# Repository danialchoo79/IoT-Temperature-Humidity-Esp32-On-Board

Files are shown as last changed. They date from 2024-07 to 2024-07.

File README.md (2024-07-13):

Schematic
PCB-Layout
3D-Front
3D-Back

Credit: made by morten

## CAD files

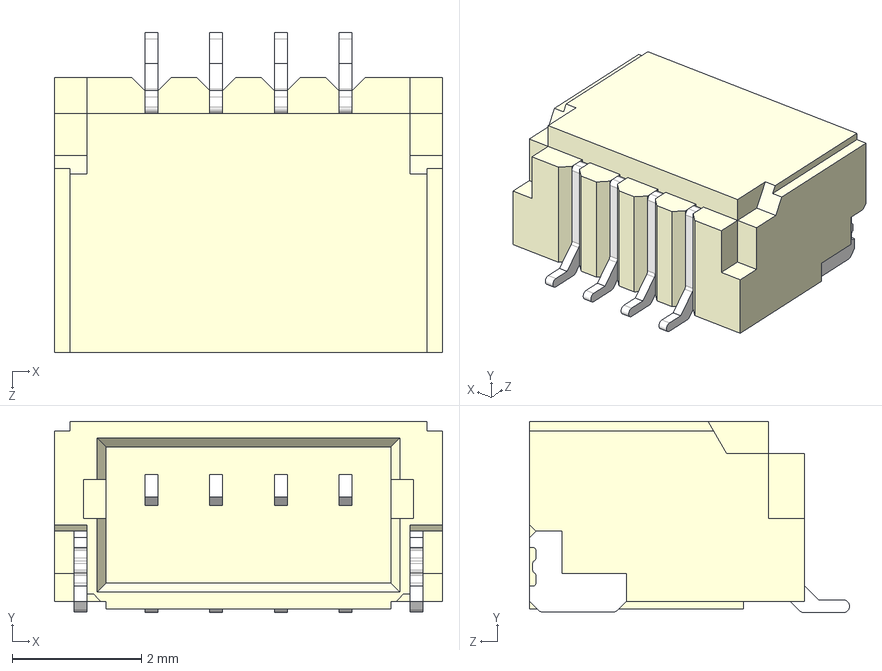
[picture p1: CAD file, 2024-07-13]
Downloaded/SM04B-SRSS-TB(LF)(SN)--3DModel-STEP-269445.STEP
6.00 x 2.96 x 4.95 mm

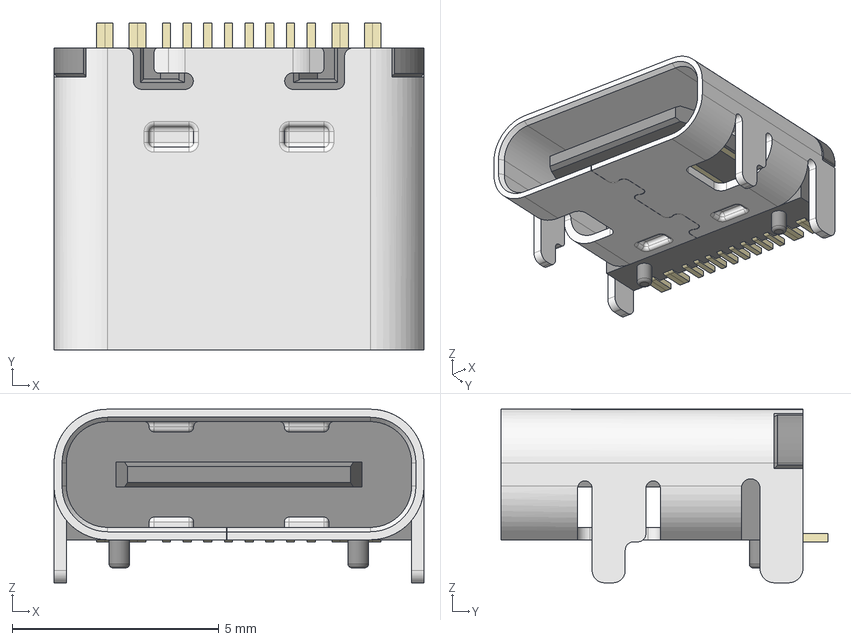
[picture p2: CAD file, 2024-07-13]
Downloaded/HRO_TYPE-C-31-M-12.step
8.95 x 7.90 x 4.20 mm

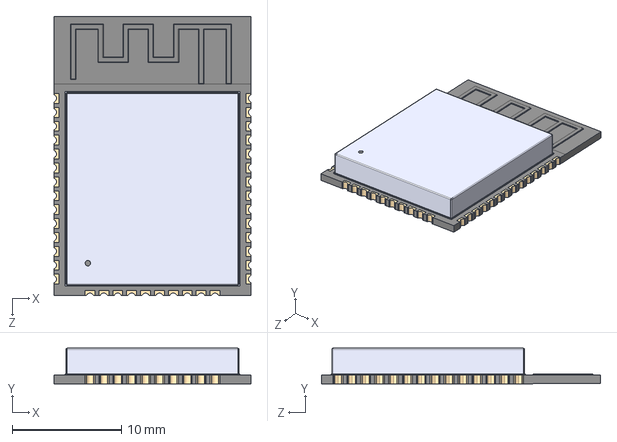
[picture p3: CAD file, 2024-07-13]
Downloaded/ESP32-WROOM-32E (16MB).STEP
18.0 x 3.25 x 25.5 mm

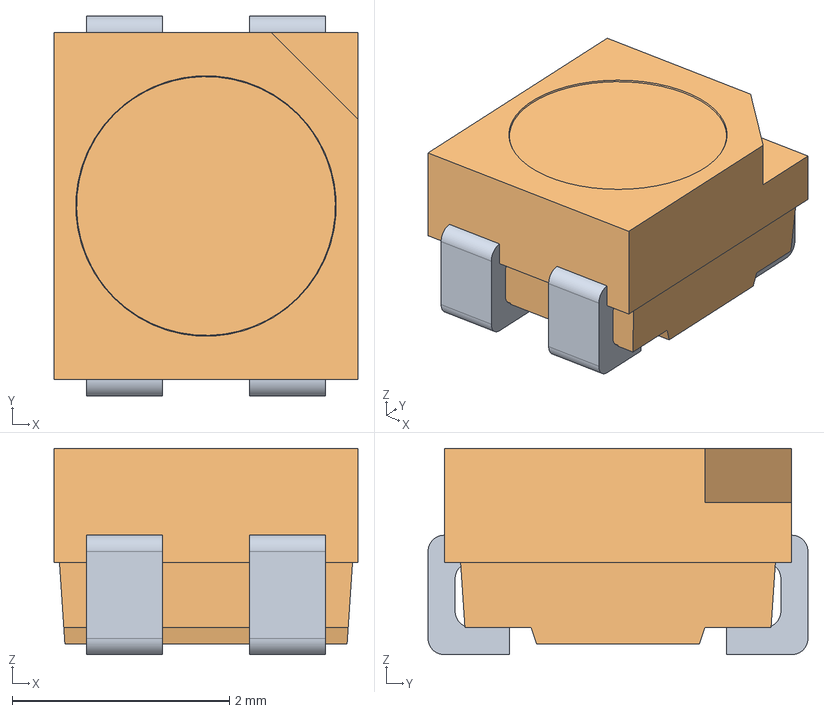
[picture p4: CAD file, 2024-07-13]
Downloaded/LV1.stp
2.80 x 3.50 x 1.90 mm

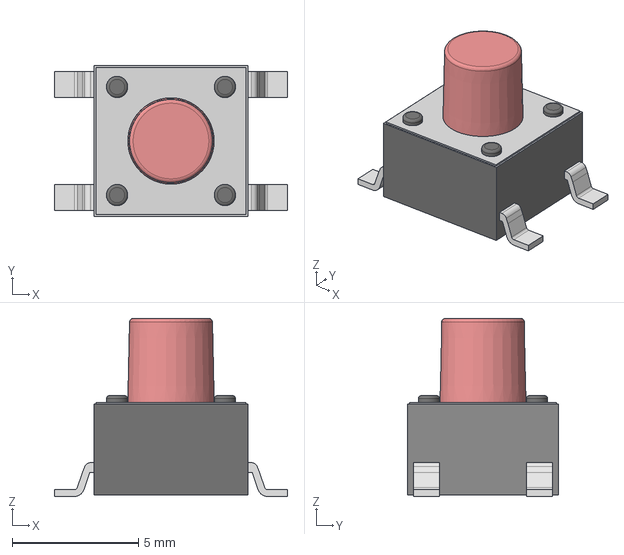
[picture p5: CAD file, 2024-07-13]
Downloaded/DTSM-63N-V-B.stp
9.25 x 5.99 x 7.07 mm

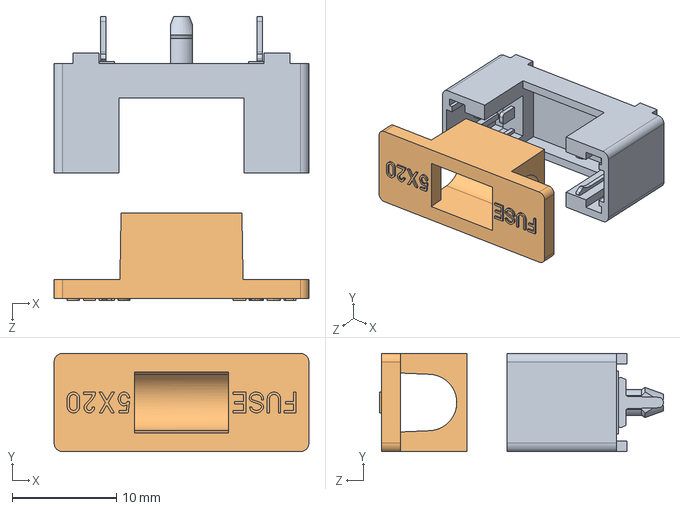
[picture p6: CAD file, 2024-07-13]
Downloaded/696105003002.stp
24.4 x 9.40 x 27.2 mm

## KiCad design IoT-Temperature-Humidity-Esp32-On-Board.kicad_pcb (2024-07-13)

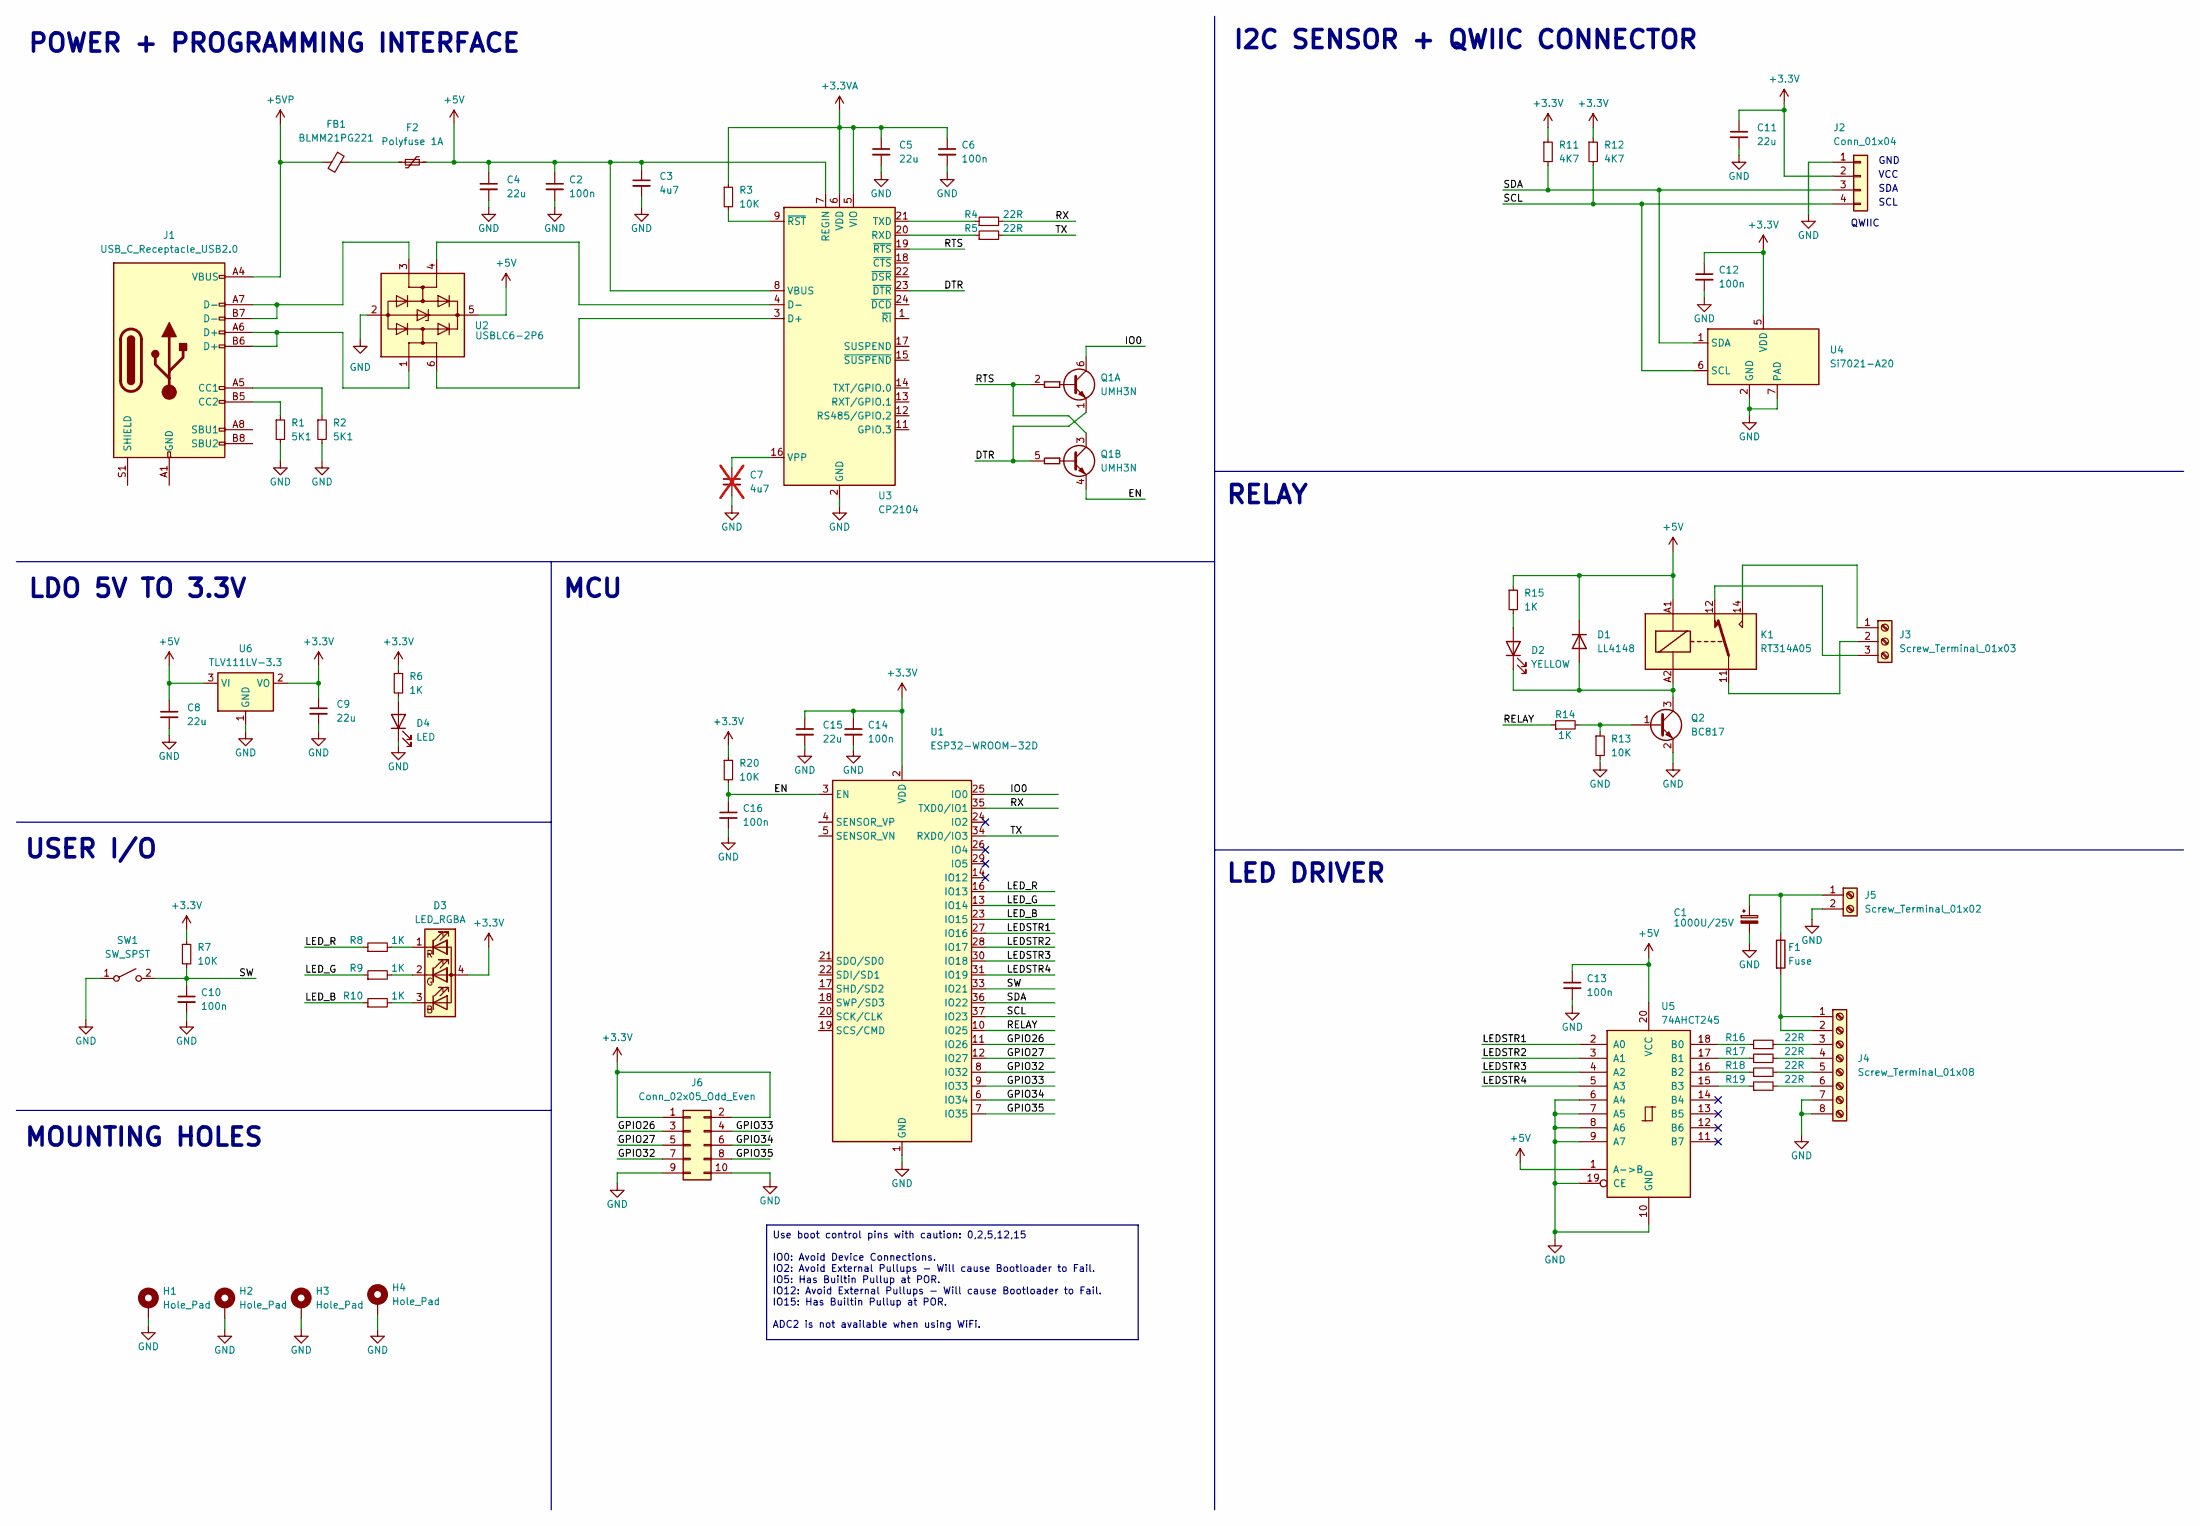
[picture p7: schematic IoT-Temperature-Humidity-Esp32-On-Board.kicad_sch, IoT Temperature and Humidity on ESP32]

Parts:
C1: 1000U/25V; CP_Radial_D10.0mm_P5.00mm
C2, C6, C10, C12, C13, C14, C16: 100n; C_0402_1005Metric_Pad0.74x0.62mm_HandSolder
C3: 4u7; C_0805_2012Metric_Pad1.18x1.45mm_HandSolder
C4, C5, C8, C9, C11, C15: 22u; C_0805_2012Metric_Pad1.18x1.45mm_HandSolder
C7: 4u7; C_0805_2012Metric_Pad1.18x1.45mm_HandSolder; not fitted
D1: LL4148; D_MiniMELF
D2: YELLOW; LED_0603_1608Metric_Pad1.05x0.95mm_HandSolder
D3: LED_RGBA; LED_RGB_Wuerth-PLCC4_3.2x2.8mm_150141M173100
D4: LED; LED_0603_1608Metric_Pad1.05x0.95mm_HandSolder
F1: Fuse; CONN2_03002_WRE
F2: Polyfuse 1A; Fuse_1206_3216Metric_Pad1.42x1.75mm_HandSolder
FB1: BLMM21PG221; L_0603_1608Metric_Pad1.05x0.95mm_HandSolder
H1, H2, H3, H4: Hole_Pad; MountingHole_3.2mm_M3_Pad_Via
J1: USB_C_Receptacle_USB2.0; USB_C_Receptacle_HRO_TYPE-C-31-M-12
J2: Conn_01x04; JST_SH_SM04B-SRSS-TB_1x04-1MP_P1.00mm_Horizontal
J3: Screw_Terminal_01x03; TerminalBlock_Phoenix_MKDS-1,5-3-5.08_1x03_P5.08mm_Horizont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
J4: Screw_Terminal_01x08; TerminalBlock_Phoenix_MKDS-1,5-8-5.08_1x08_P5.08mm_Horizont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
J5: Screw_Terminal_01x02; TerminalBlock_Phoenix_MKDS-1,5-2-5.08_1x02_P5.08mm_Horizont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
J6: Conn_02x05_Odd_Even; PinHeader_2x05_P2.54mm_Vertical
K1: RT314A05; Relay_SPDT_Schrack-RT1-16A-FormC_RM5mm
Q1: UMH3N; SOT-363_SC-70-6
Q2: BC817; SOT-23
R1, R2: 5K1; R_0402_1005Metric_Pad0.72x0.64mm_HandSolder
R3, R7, R13, R20: 10K; R_0402_1005Metric_Pad0.72x0.64mm_HandSolder
R4, R5, R16, R17, R18, R19: 22R; R_0402_1005Metric_Pad0.72x0.64mm_HandSolder
R6, R8, R9, R10, R14, R15: 1K; R_0402_1005Metric_Pad0.72x0.64mm_HandSolder
R11, R12: 4K7; R_0402_1005Metric_Pad0.72x0.64mm_HandSolder
SW1: SW_SPST; SW_Push_1P1T_NO_6x6mm_H9.5mm
U1: ESP32-WROOM-32D
U2: USBLC6-2P6; SOT-666
U3: CP2104; QFN-24-1EP_4x4mm_P0.5mm_EP2.6x2.6mm
U4: Si7021-A20; DFN-6-1EP_3x3mm_P1mm_EP1.5x2.4mm
U5: 74AHCT245; DIP-20_W7.62mm
U6: TLV111LV-3.3; SOT-223-3_TabPin2

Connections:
+3.3V: C9.1, C11.1, C12.1, C14.1, C15.1, D3.4 (A), J2.2, J6.1, J6.2, R6.1, R7.1, R11.1, R12.1, R20.1, U1.2 (VDD), U4.5 (VDD), U6.2 (VO)
+3.3VA: C5.1, C6.1, R3.1, U3.5 (VIO), U3.6 (VDD)
+5VP: FB1.2, J1.A4 (VBUS), J1.A9 (VBUS), J1.B4 (VBUS), J1.B9 (VBUS)
/DTR: Q1.1 (E1), Q1.5 (B2), U3.23 (~DTR)
/EN: C16.1, Q1.4 (E2), R20.2, U1.3 (EN)
/GPIO26: J6.3, U1.11 (IO26)
/GPIO27: J6.5, U1.12 (IO27)
/GPIO32: J6.7, U1.8 (IO32)
/GPIO33: J6.4, U1.9 (IO33)
/GPIO34: J6.6, U1.6 (IO34)
/GPIO35: J6.8, U1.7 (IO35)
/IO0: Q1.6 (C1), U1.25 (IO0)
/LEDSTR1: U1.27 (IO16), U5.2 (A0)
/LEDSTR2: U1.28 (IO17), U5.3 (A1)
/LEDSTR3: U1.30 (IO18), U5.4 (A2)
/LEDSTR4: U1.31 (IO19), U5.5 (A3)
/LED_B: R10.1, U1.23 (IO15)
/LED_G: R9.1, U1.13 (IO14)
/LED_R: R8.1, U1.16 (IO13)
/RELAY: R14.1, U1.10 (IO25)
/RTS: Q1.2 (B1), Q1.3 (C2), U3.19 (~RTS)
/RX: R4.2, U1.35 (TXD0/IO1)
/SCL: J2.4, R12.2, U1.37 (IO23), U4.6 (SCL)
/SDA: J2.3, R11.2, U1.36 (IO22), U4.1 (SDA)
/SW: C10.1, R7.2, SW1.2 (B), U1.33 (IO21)
/TX: R5.2, U1.34 (RXD0/IO3)
GND: C1.2, C2.2, C3.2, C4.2, C5.2, C6.2, C7.2, C8.2, C9.2, C10.2, C11.2, C12.2, C13.2, C14.2, C15.2, C16.2, D4.1 (K), H1.1, H2.1, H3.1, H4.1, J2.1, J4.7, J4.8, J5.2, J6.9, J6.10, Q2.2 (E), R1.2, R2.2, R13.2, SW1.1 (A), U1.1 (GND), U1.15 (GND), U1.38 (GND), U1.39 (GND), U2.2 (GND), U3.2 (GND), U3.25 (GND), U4.2 (GND), U4.7 (PAD), U5.6 (A4), U5.7 (A5), U5.8 (A6), U5.9 (A7), U5.10 (GND), U5.19 (CE), U6.1 (GND)
unnamed: D1.2 (A), D2.1 (K), K1.A2, Q2.3 (C)
unnamed: D2.2 (A), R15.2
unnamed: D3.3 (BK), R10.2
unnamed: D3.2 (GK), R9.2
unnamed: D3.1 (RK), R8.2
unnamed: D4.2 (A), R6.2
unnamed: F2.2, FB1.1
unnamed: J1.A5 (CC1), R2.1
unnamed: J1.B5 (CC2), R1.1
unnamed: J1.A7 (D-), J1.B7 (D-), U2.3 (I/O2)
unnamed: J1.A1 (GND), J1.A12 (GND), J1.B1 (GND), J1.B12 (GND)
unnamed: J3.1, K1.14
unnamed: J3.2, K1.11
unnamed: J3.3, K1.12
unnamed: F1.2, J4.1, J4.2
unnamed: J4.3, R16.2
unnamed: J4.4, R17.2
unnamed: J4.5, R18.2
unnamed: J4.6, R19.2
unnamed: C1.1, F1.1, J5.1
unnamed: Q2.1 (B), R13.1, R14.2
unnamed: U2.6 (I/O1), U3.3 (D+)
unnamed: U2.4 (I/O2), U3.4 (D-)
unnamed: R5.1, U3.20 (RXD)
unnamed: R4.1, U3.21 (TXD)
unnamed: C7.1, U3.16 (VPP)
unnamed: R3.2, U3.9 (~RST)
unnamed: R16.1, U5.18 (B0)
unnamed: R17.1, U5.17 (B1)
unnamed: R18.1, U5.16 (B2)
unnamed: R19.1, U5.15 (B3)

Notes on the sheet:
Use boot control pins with caution: 0,2,5,12,15 IO0: Avoid Device Connections. IO2: Avoid External Pullups - Will cause Bootloader to Fail. IO5: Has Builtin Pullup at POR. IO12: Avoid External Pullups - Will cause Bootloader to Fail. IO15: Has Builtin Pullup at POR. ADC2 is not available when using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
LED DRIVER
MOUNTING HOLES
USER I/O
POWER + PROGRAMMING INTERFACE
SCL
SDA
I2C SENSOR + QWIIC CONNECTOR
RELAY
VCC
GND
MCU
LDO 5V TO 3.3V
QWIIC

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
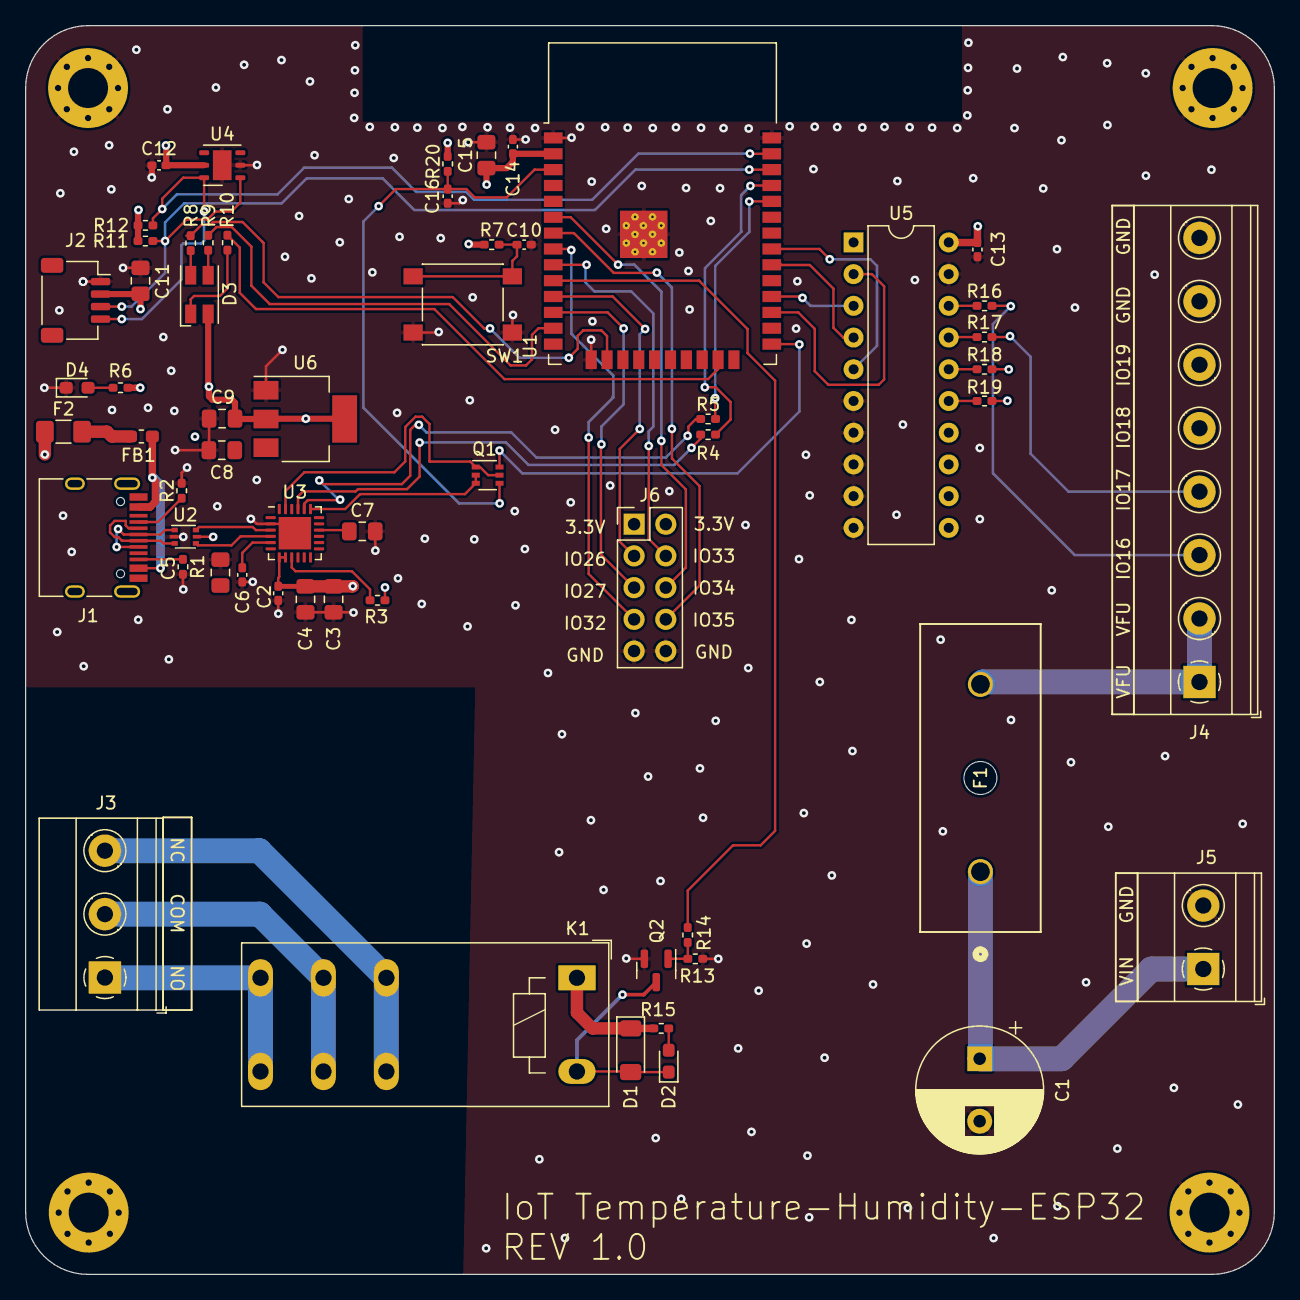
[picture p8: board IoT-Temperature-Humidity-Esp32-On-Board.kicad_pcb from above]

Board: 4 copper layers, 100.0 x 100.0 mm, 63 parts (0 on the bottom side), 59 nets.
